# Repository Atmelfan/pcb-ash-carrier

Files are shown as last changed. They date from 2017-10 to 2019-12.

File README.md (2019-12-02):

# pcb-ash-carrier
ASH jetson TX2 carrier board. Imported from ASH-MKII

Main controller board for my octapod robot. 

[Schematic](https://raw.githubusercontent.com/Atmelfan/pcb-ash-carrier/master/schematic.PDF)

SAM Version revision 1 (May 2019):

IMAGE ALT TEXT (http://www.youtube.com/watch?v=Iza4ah-3IUo "SAM the octapod")

Carrier board:
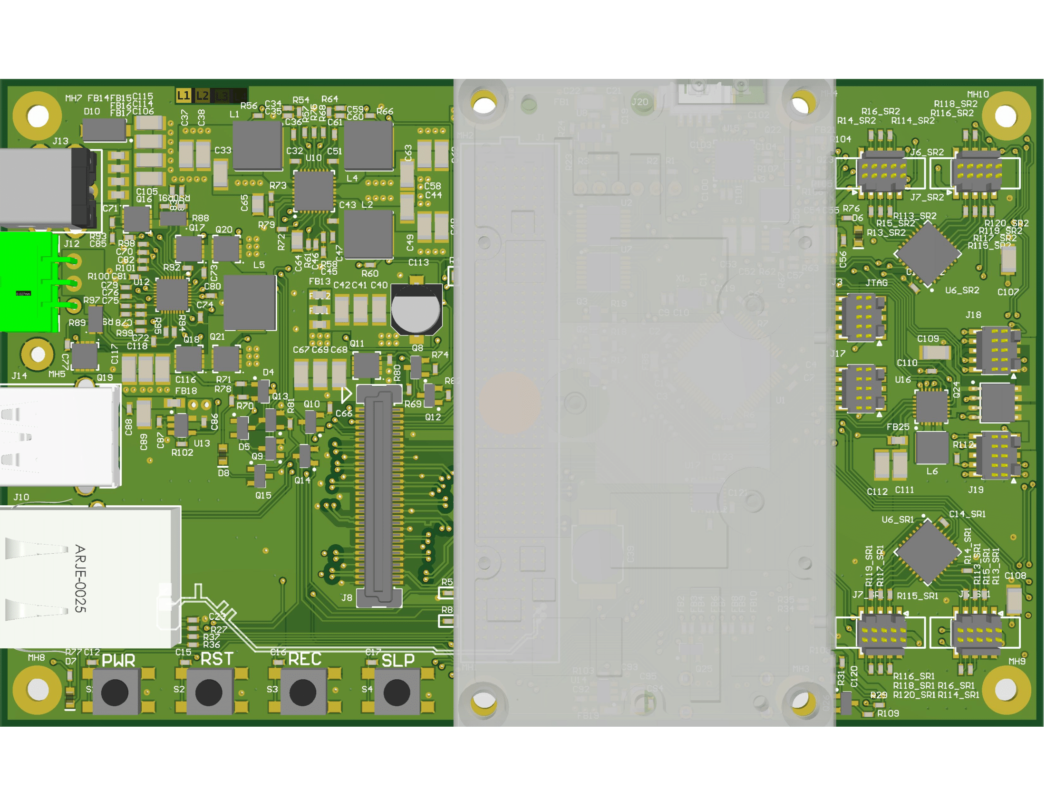
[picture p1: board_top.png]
Top side

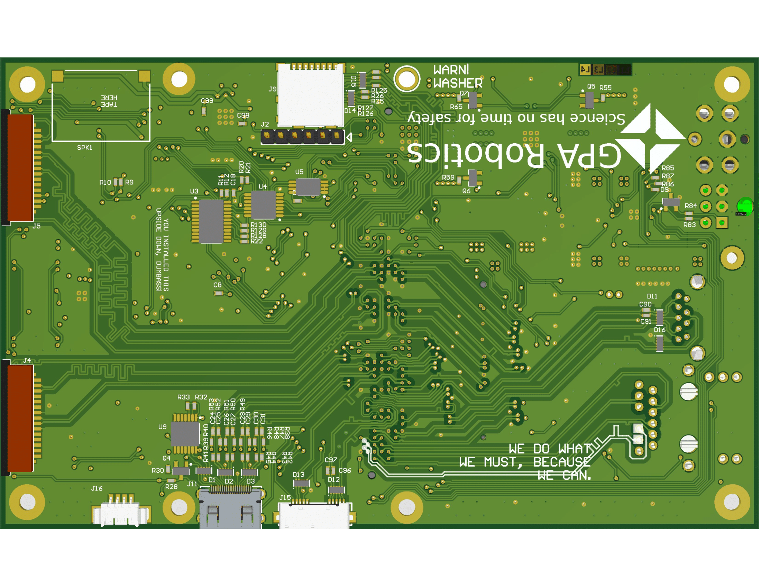
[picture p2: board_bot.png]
Bottom side


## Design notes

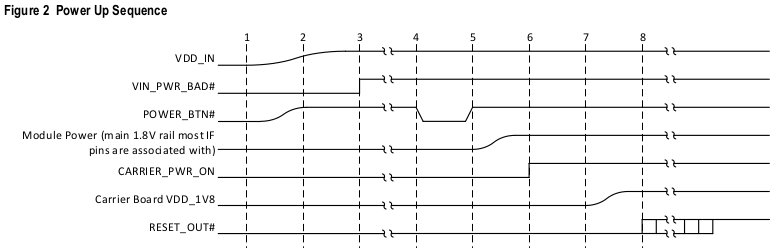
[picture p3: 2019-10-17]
tx_power_up.png

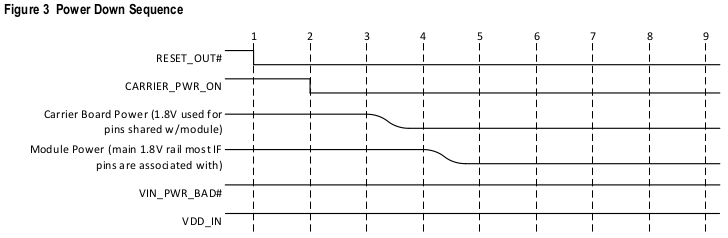
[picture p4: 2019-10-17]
tx2_power_down.png

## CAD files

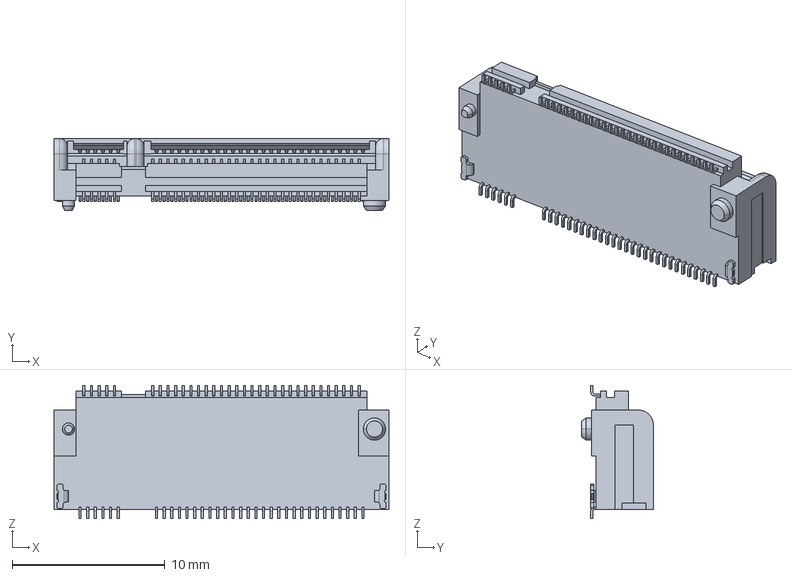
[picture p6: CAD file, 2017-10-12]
3d_models/c-2199230-5-b1-3d.stp
21.9 x 4.70 x 8.70 mm

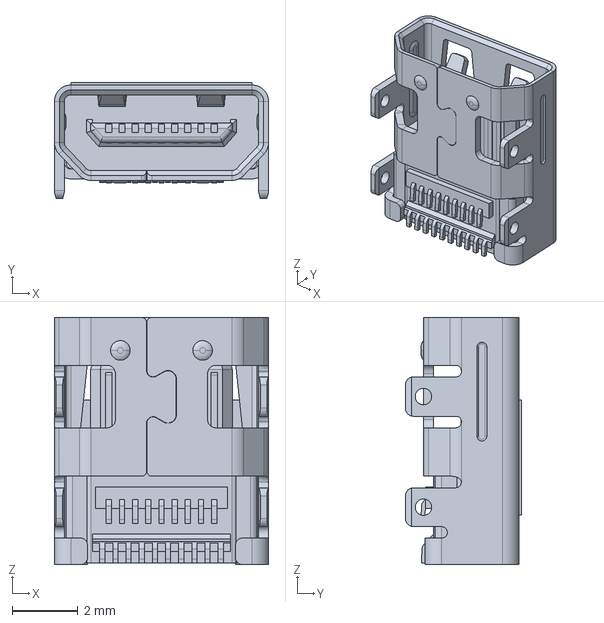
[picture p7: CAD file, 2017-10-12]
3d_models/10118242-001RLF.STP
6.50 x 3.53 x 7.50 mm

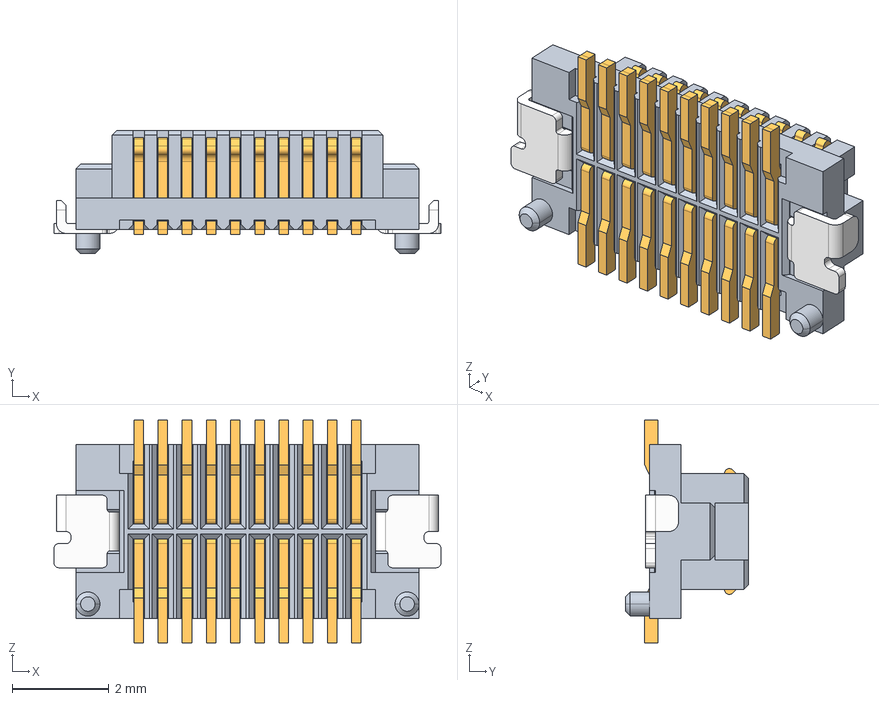
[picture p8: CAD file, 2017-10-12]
3d_models/10132798-021100LF.stp
8.00 x 2.55 x 4.60 mm
30H-20PIN-M-H
30H-M-TERMINAL x 10

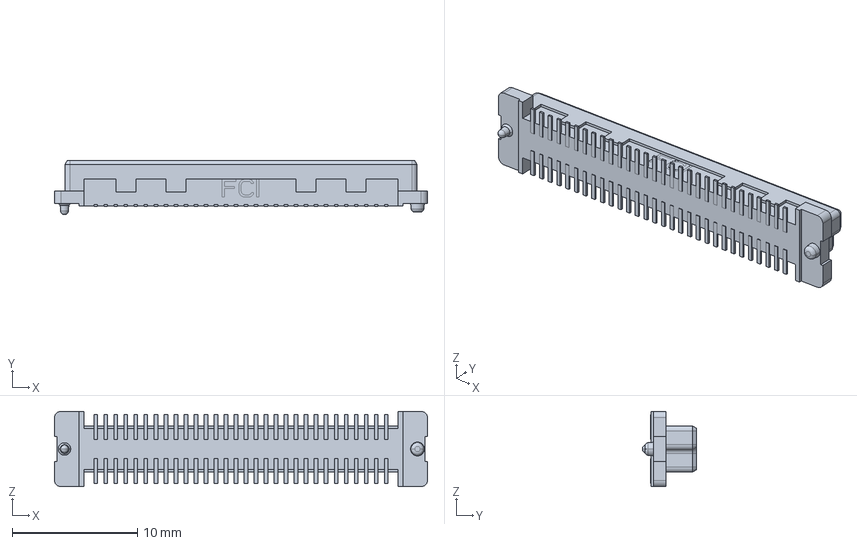
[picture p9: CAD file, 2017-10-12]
3d_models/s61082-061x0xxx.stp
29.8 x 4.35 x 6.00 mm

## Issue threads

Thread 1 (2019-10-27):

PSU sequence error

Atmelfan, 2019-10-27:
The PSU start sequence does not complete due to a missing pull-up.

Fixed in rev 1 prototype. Update schematic.

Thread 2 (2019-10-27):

Missing values

Atmelfan, 2019-10-27:
A lot of components (resistors in particular) does not have their final value.

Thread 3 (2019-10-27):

USB does not enable VBUS

Atmelfan, 2019-10-27:
USB VBUS never gets powered by the carrier. Most likely an error with the VBUS_EN# pins polarity or missing pull-up?

Might also be a firmware error.

Atmelfan, 2020-04-07:
Firmware error, the dbt requires a vbus-regulator which does not exist on the board.

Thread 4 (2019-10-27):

Voltage translator does not work/prevent boot

Atmelfan, 2019-10-27:
Voltage level converters U2/U7 keeps the TX2 from booting. Most likely caused by UART1_TX being pulled up by U2 on boot.

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

Atmelfan, 2019-10-27:
UART7 is also affected by U7.
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

Atmelfan, 2020-01-20:
Most of these issues is caused by LSF/TXB0204 are used to translate both Push-poll and Open-drain IO:s which is incorrect. Split the IO:s between multiple appropriate translators.

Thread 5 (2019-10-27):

GYRO has incorrect footprint and uses a NRND part

Atmelfan, 2019-10-27:
Switch MP6000 to MP9250 (or equivalent) with a correct footprint.

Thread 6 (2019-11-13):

Add RS485 transciever(s)

Atmelfan, 2019-11-13:
New servos uses RS485 for communication and will thus require a transciever on the carrier.
Prefably both the jetson TX2 and the onboard MCU will be able to commicate with the servos (or eachother).

Possible solutions:
1. Jetson TX2 and the MCU get their own transciever connected to a shared bus.
2. A single transciever sharedby jetson and the MCU.
3. MCU forwards commication from serial interface (will require a custom driver in TX2 firmware)

ATM option 1 looks like the best solution.

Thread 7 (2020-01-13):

Add servo ports for eyes

Atmelfan, 2020-01-13:
Both right and left servo control has unused PWM outputs.

Supply should be taken from VBAT with its own step-down converter. Alternatively tap into VSYS_5V0 but this could result in a lot of noise on USB ports.

Atmelfan, 2020-04-07:
Added to pcb-ash-power

Closed 2020-04-07.

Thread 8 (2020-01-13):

Replace NVM screw standoffss with solder standoffs

Atmelfan, 2020-01-13:
^

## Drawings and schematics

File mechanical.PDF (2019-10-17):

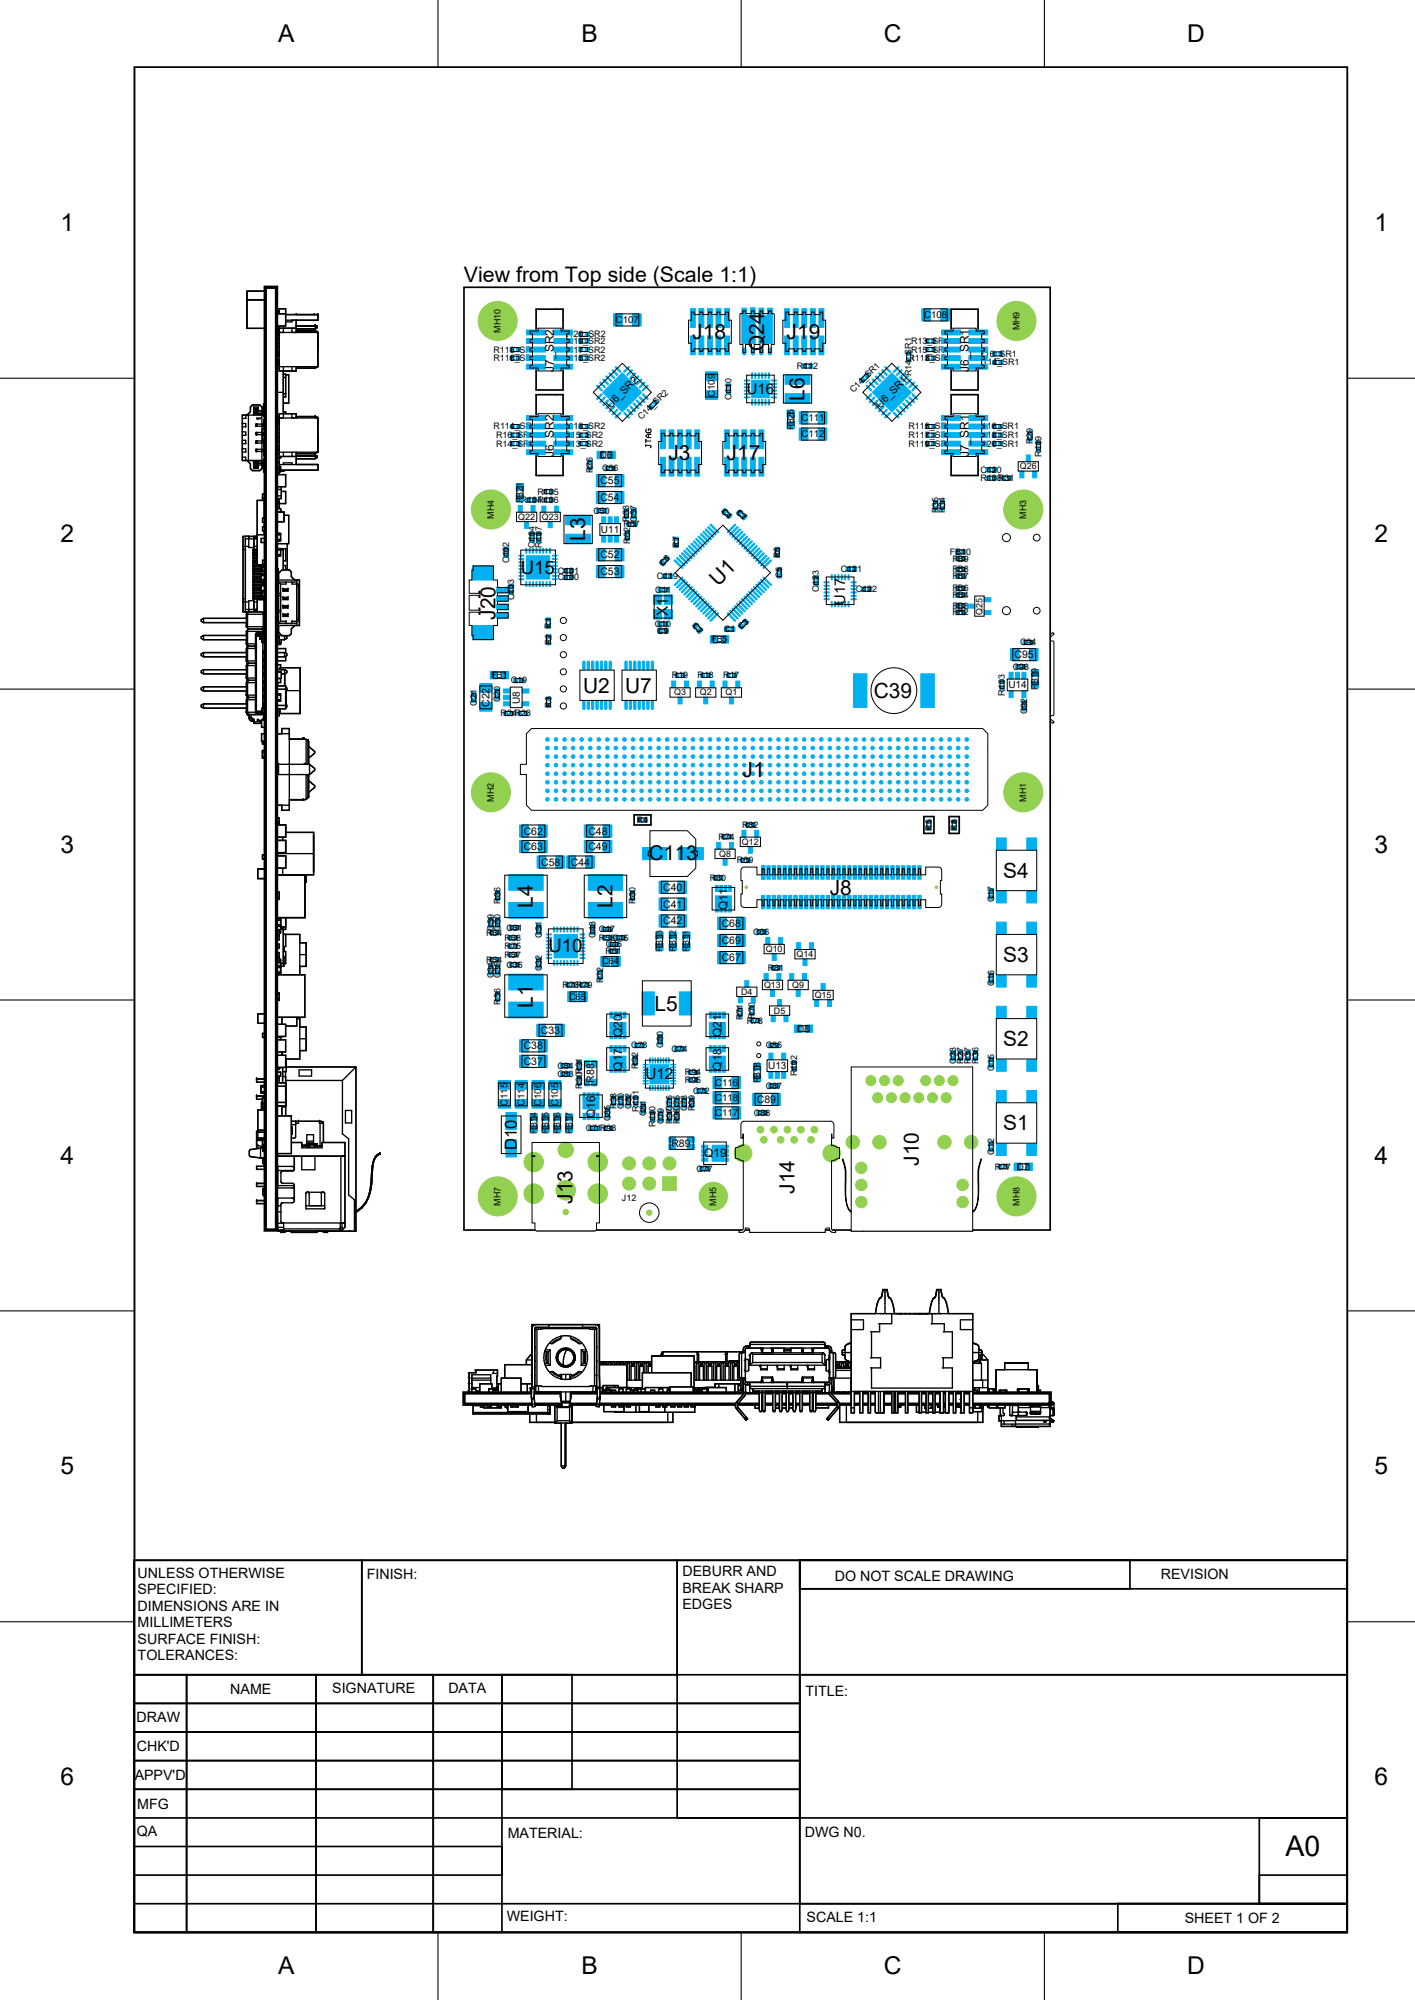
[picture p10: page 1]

View from Top side (Scale 1:1)

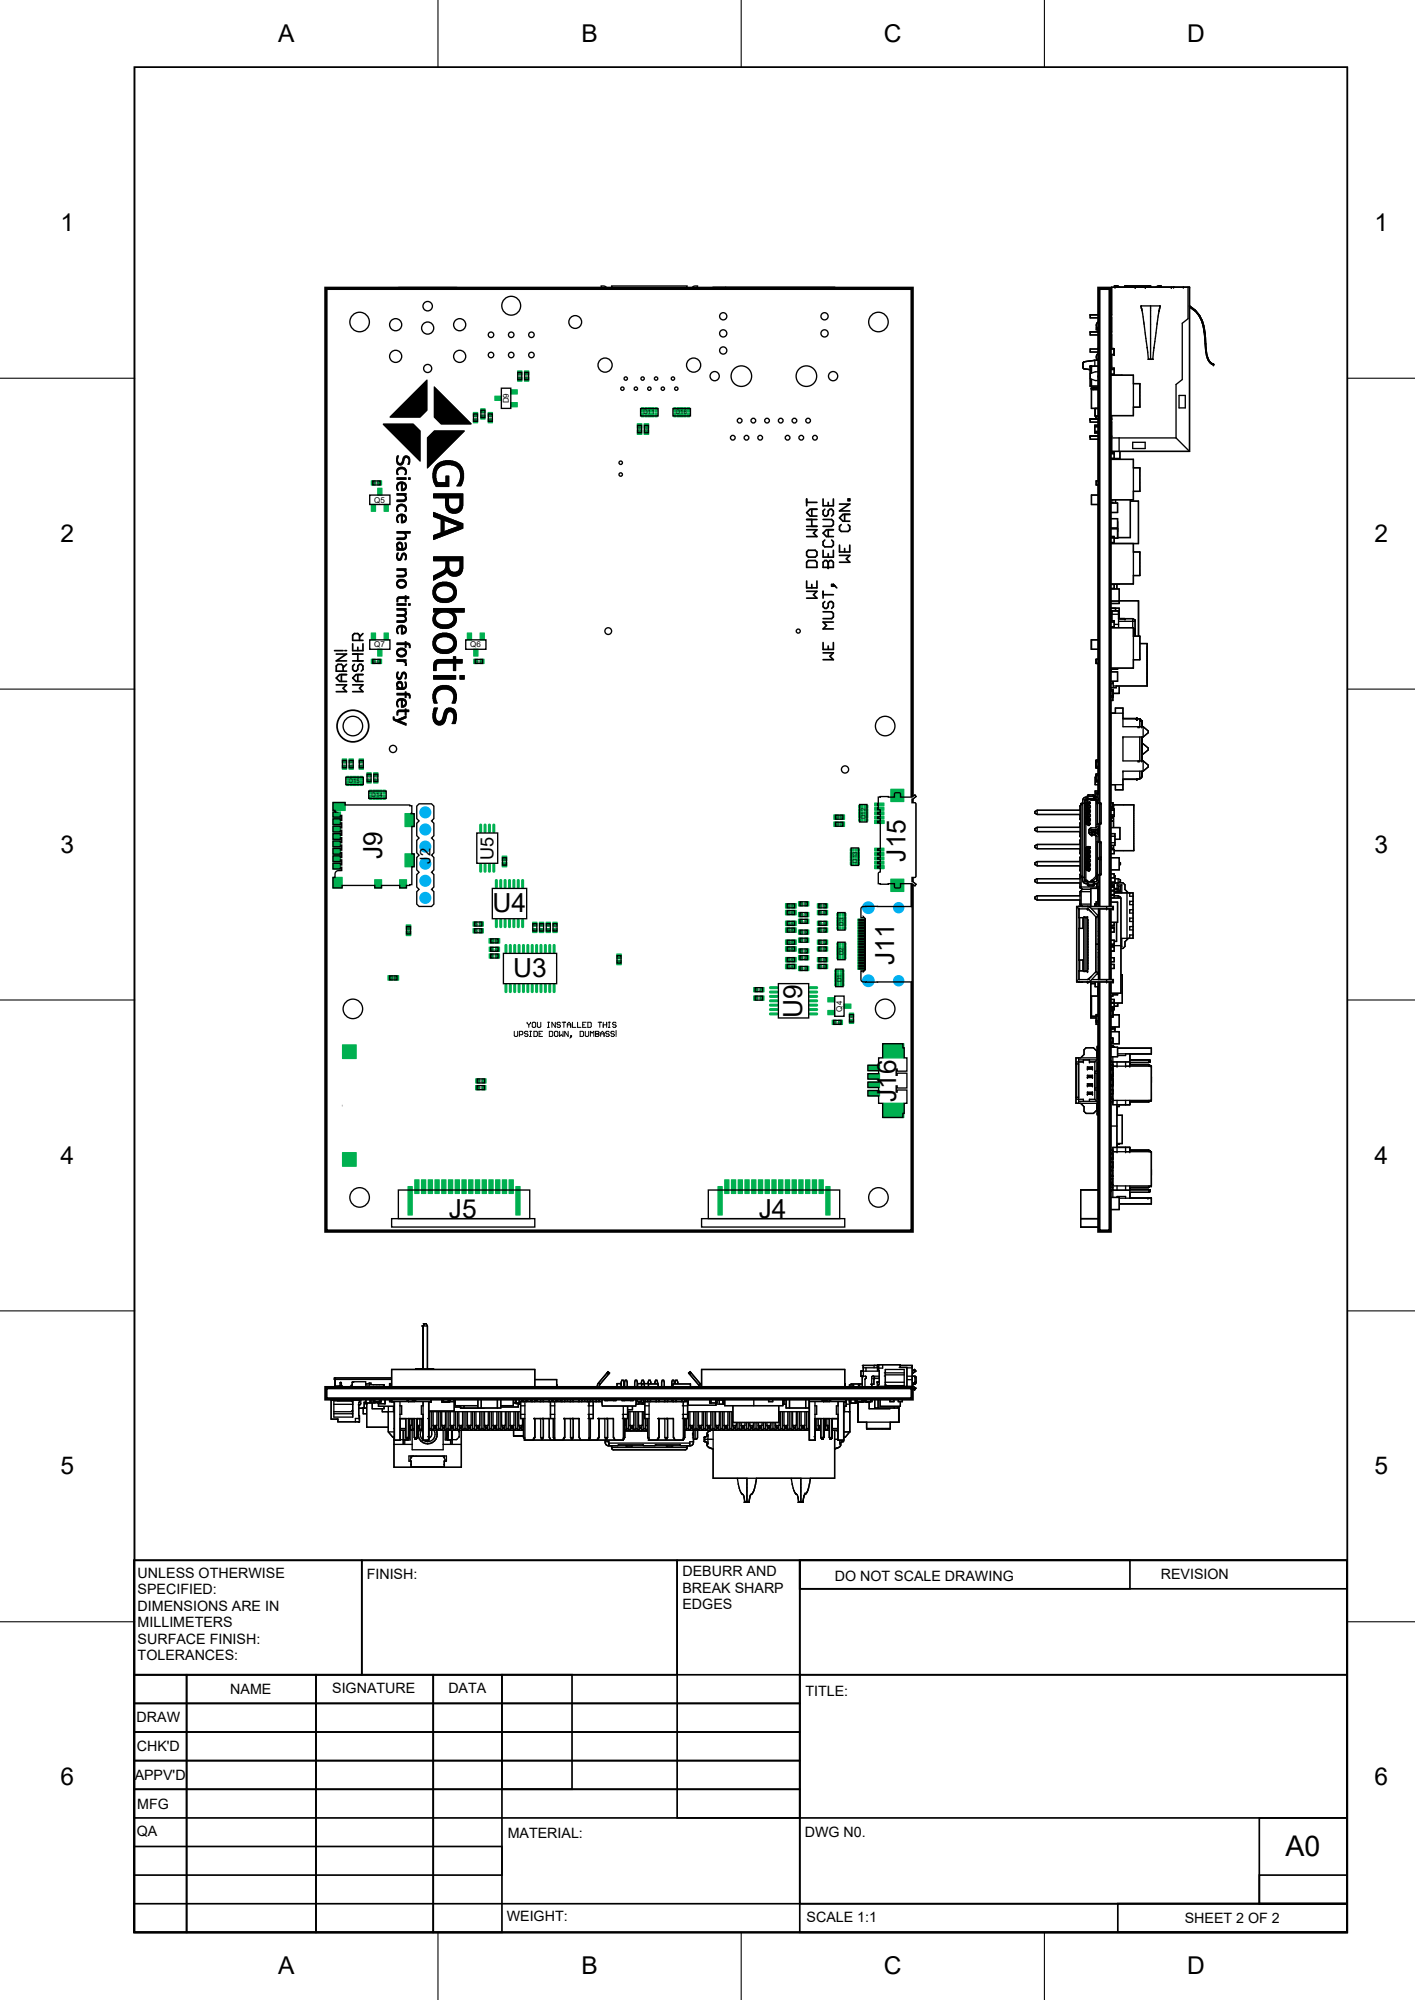
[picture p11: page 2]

NAME | SIGNATURE | DATA | | | | TITLE:

DRAW
CHK'D

APPV'D
MFG
QA | | | | MATERIAL: | DWG N0. | A0

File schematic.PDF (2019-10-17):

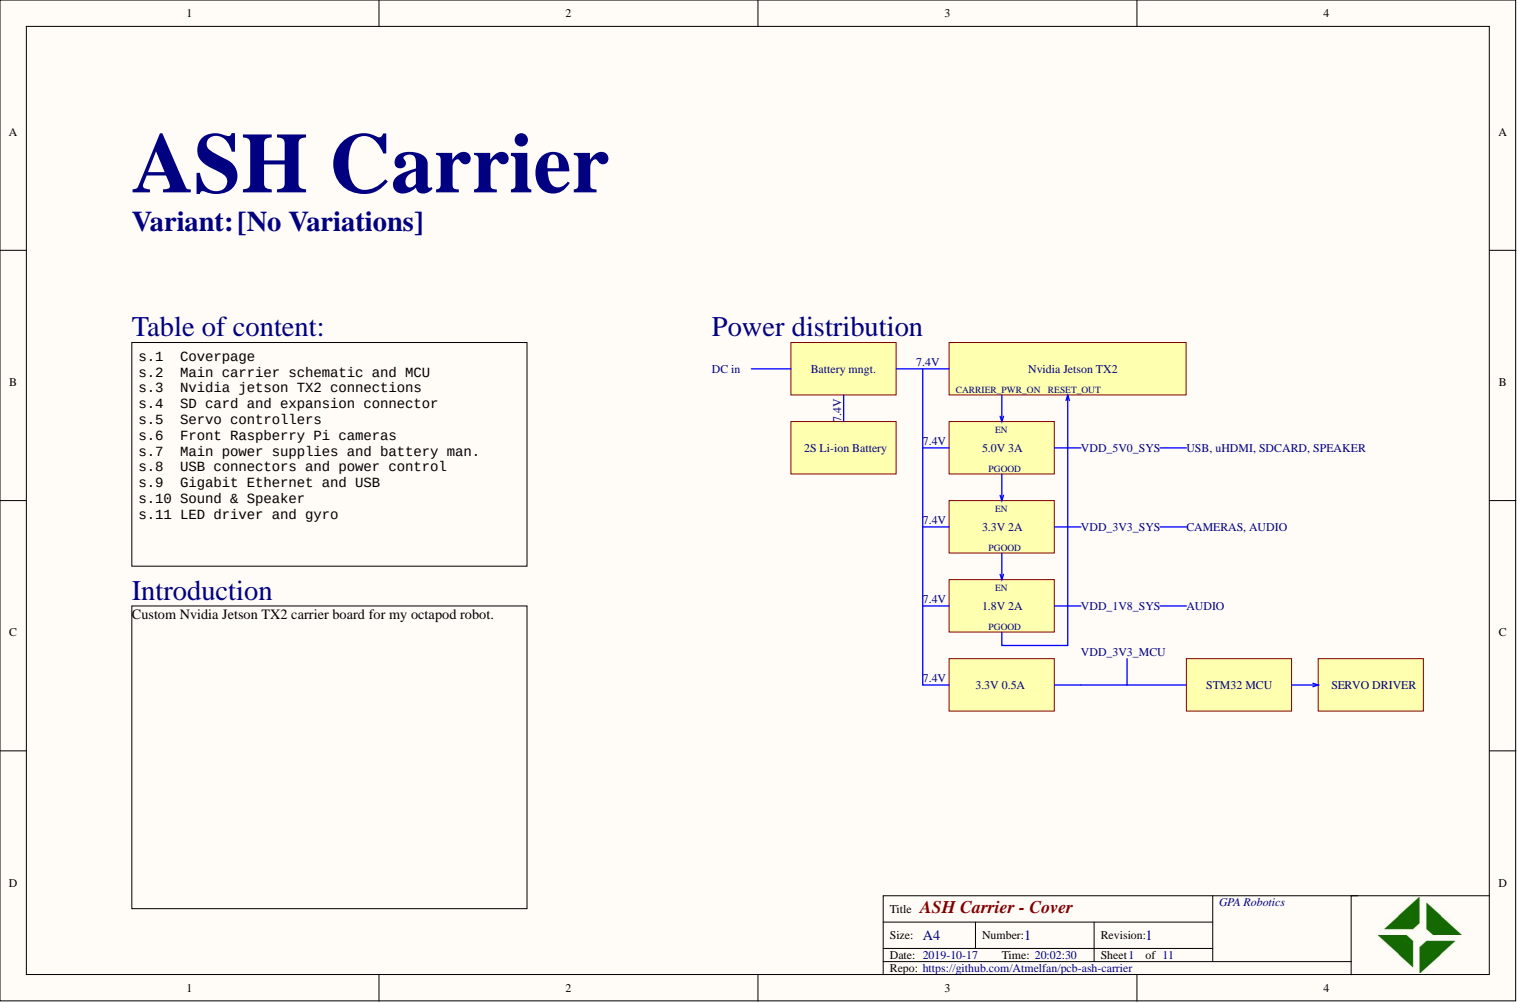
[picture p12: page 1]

s.10 Sound & Speaker
s.11 LED driver and gyro

USB, uHDMI, SDCARD, SPEAKER

Custom Nvidia Jetson TX2 carrier board for my octapod robot.

Title ASH Carrier - Cover | GPA Robotics

Size: A4 | Number: | Revision:
Date: 2019-10-17 Time: 20:02:30 | | Sheet of

https://github.com/Atmelfan/pcb-ash-carrier

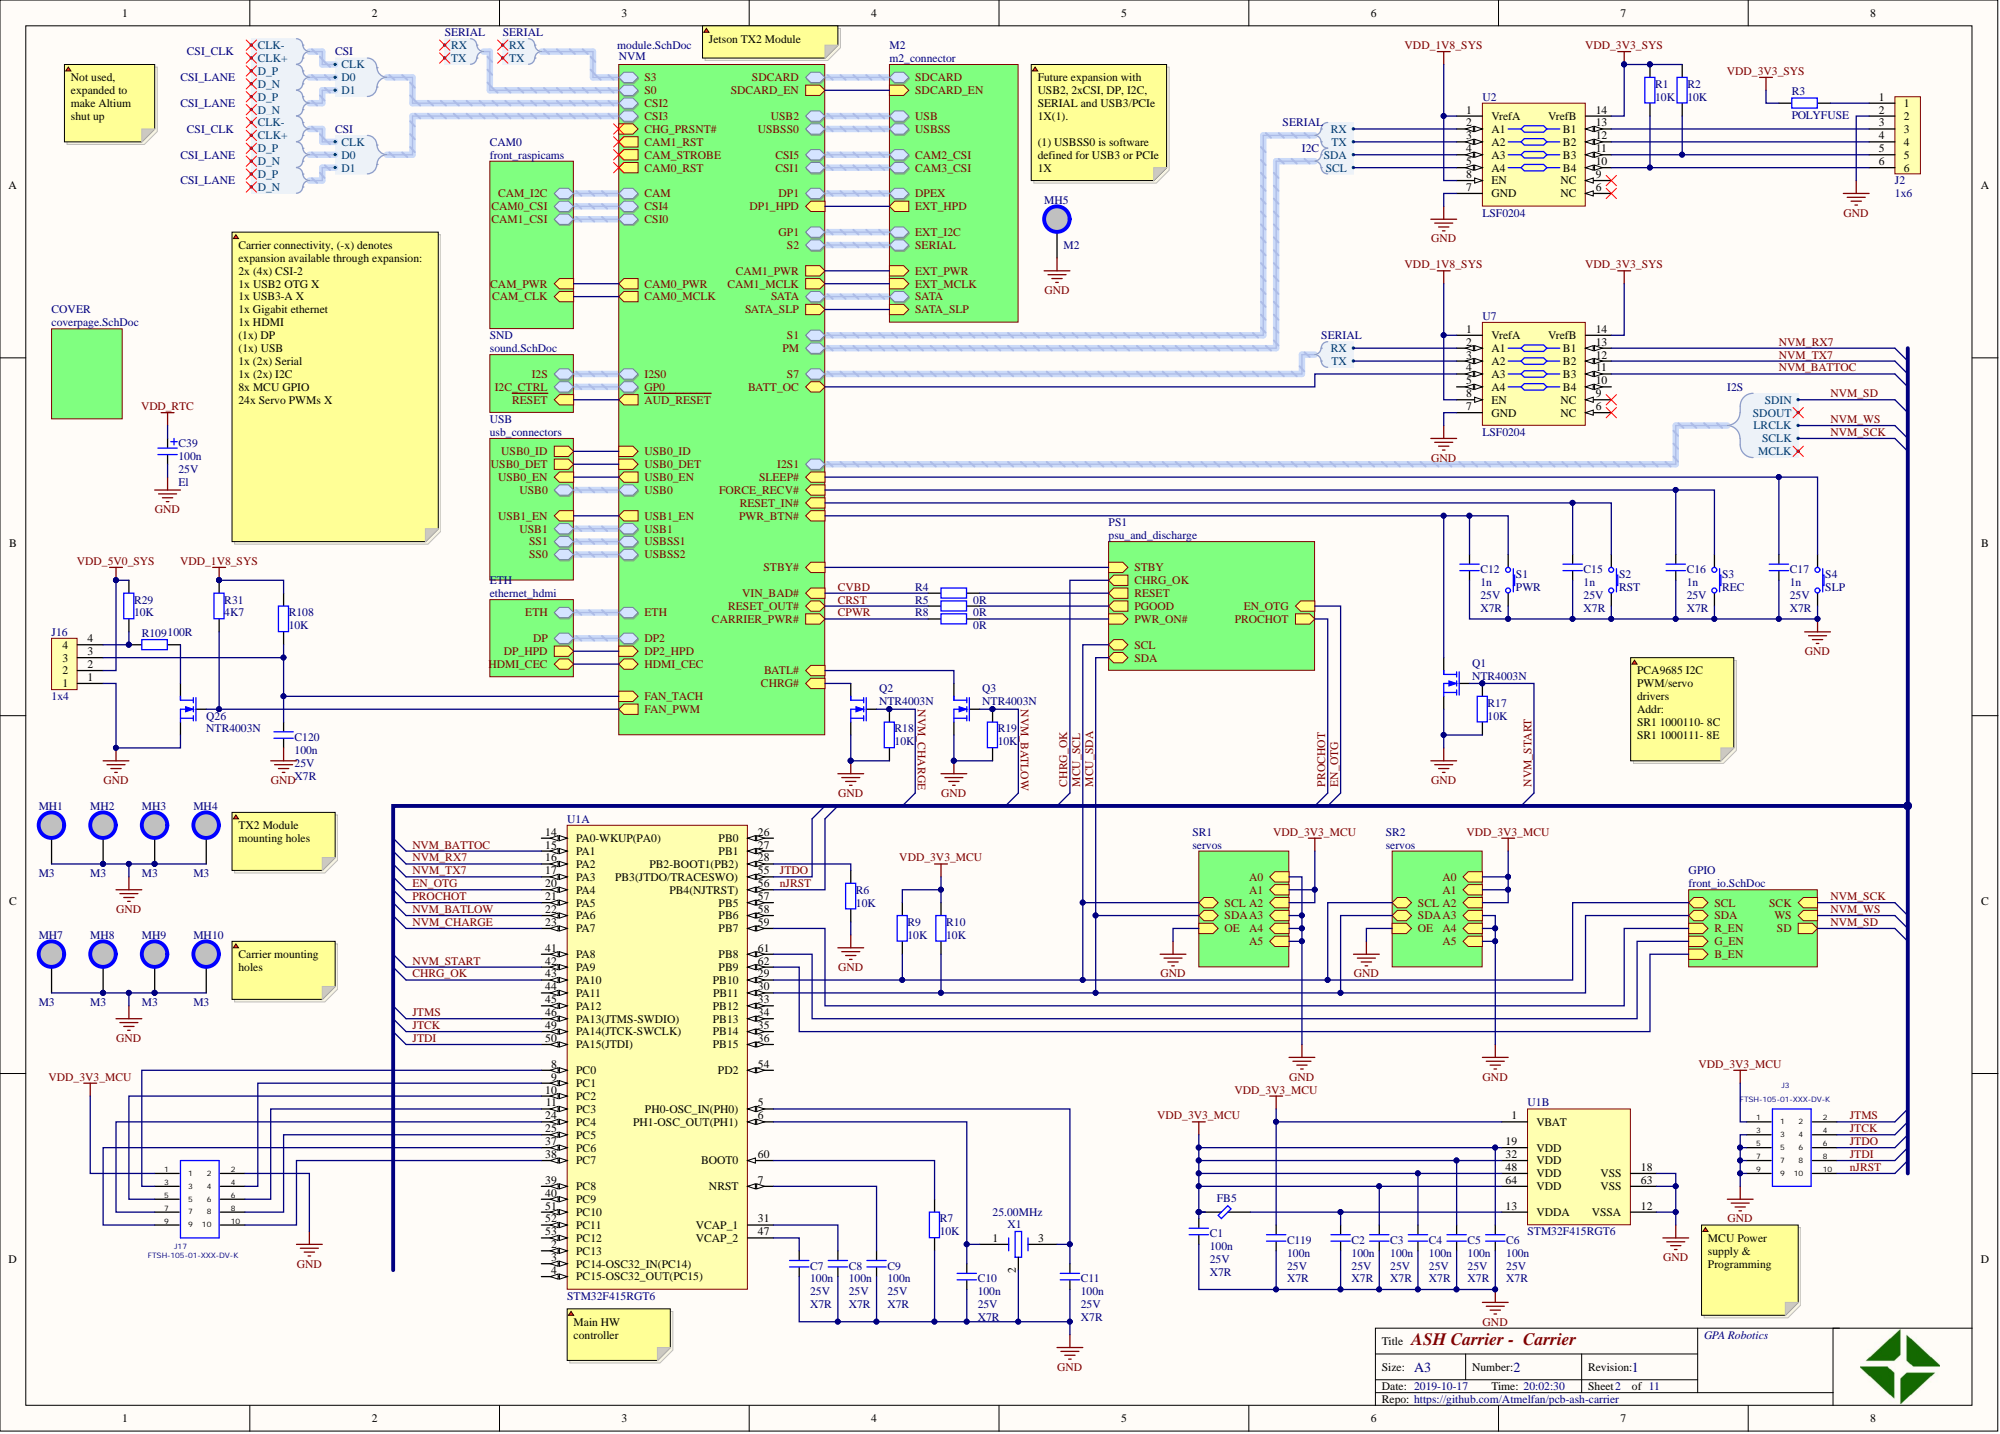
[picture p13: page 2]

(1) USBSS0 is software
defined for USB3 or PCIe

CRST R5 | 0R
CPWR R8 | 0R

SDA A3 | NVM_WS
OE A4 A5 | | NVM_SD

PC1 9
PC2 10

5 5 6 | 6 | PC9 40
7 7 8 | 8 | PC10 51
9 9 10 | 10 | PC11 52

PC15-OSC32_OUT(PC15) 4 | C10 | X7R | X7R | X7R | X7R | X7R | X7R

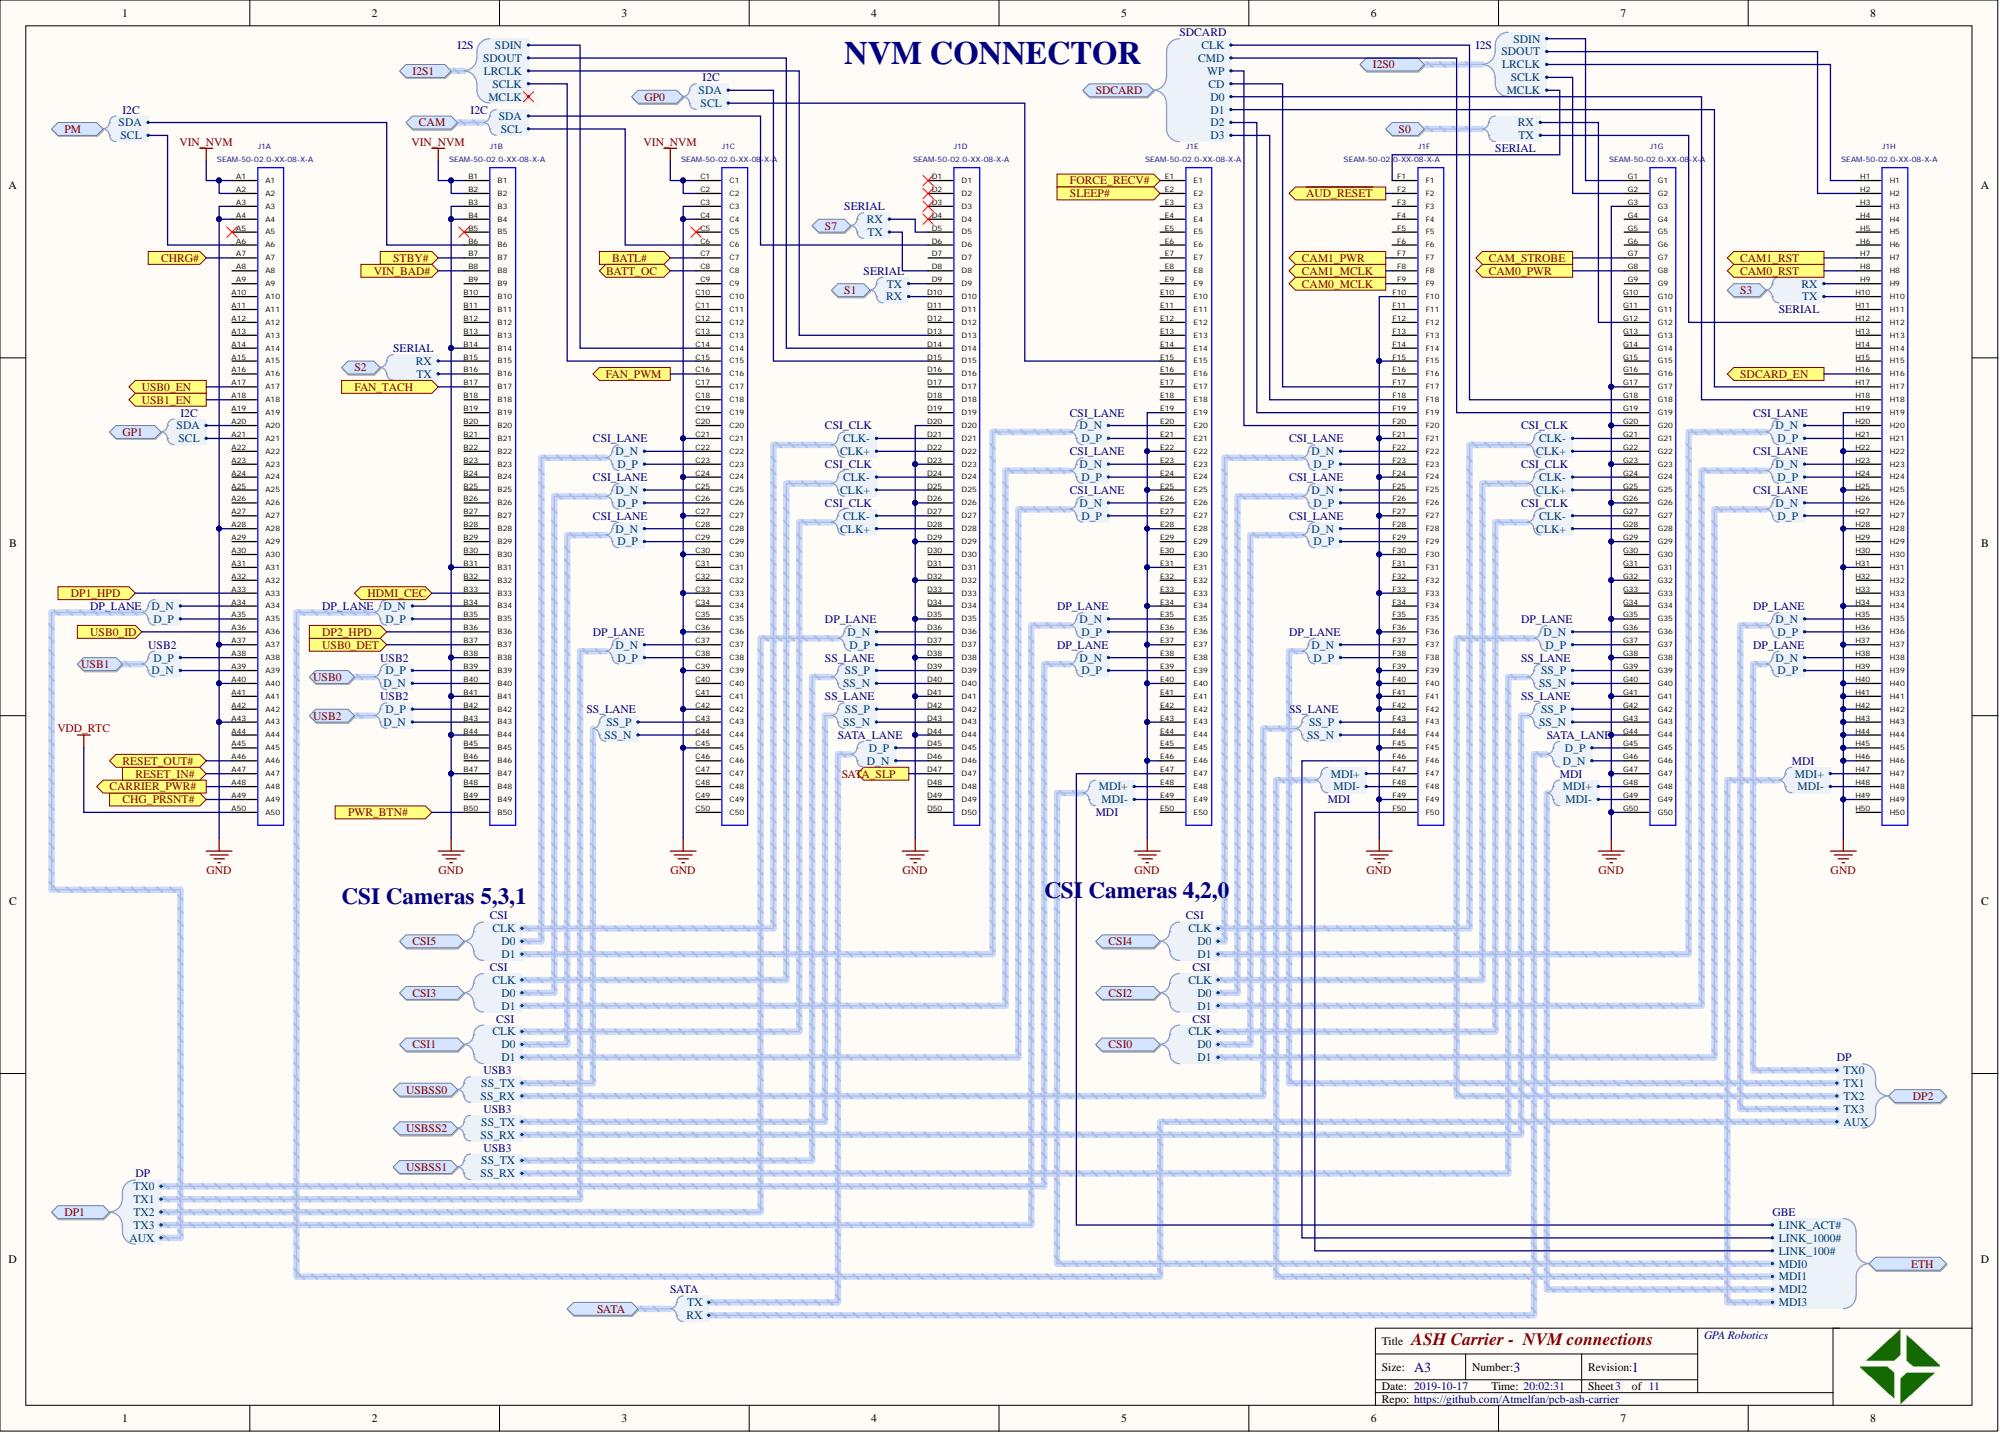
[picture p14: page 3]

SDOUT

I2S0 LRCLK

SEAM-50-02.0-XX-08-X-A | J1D

ASH Carrier - NVM connections
Title

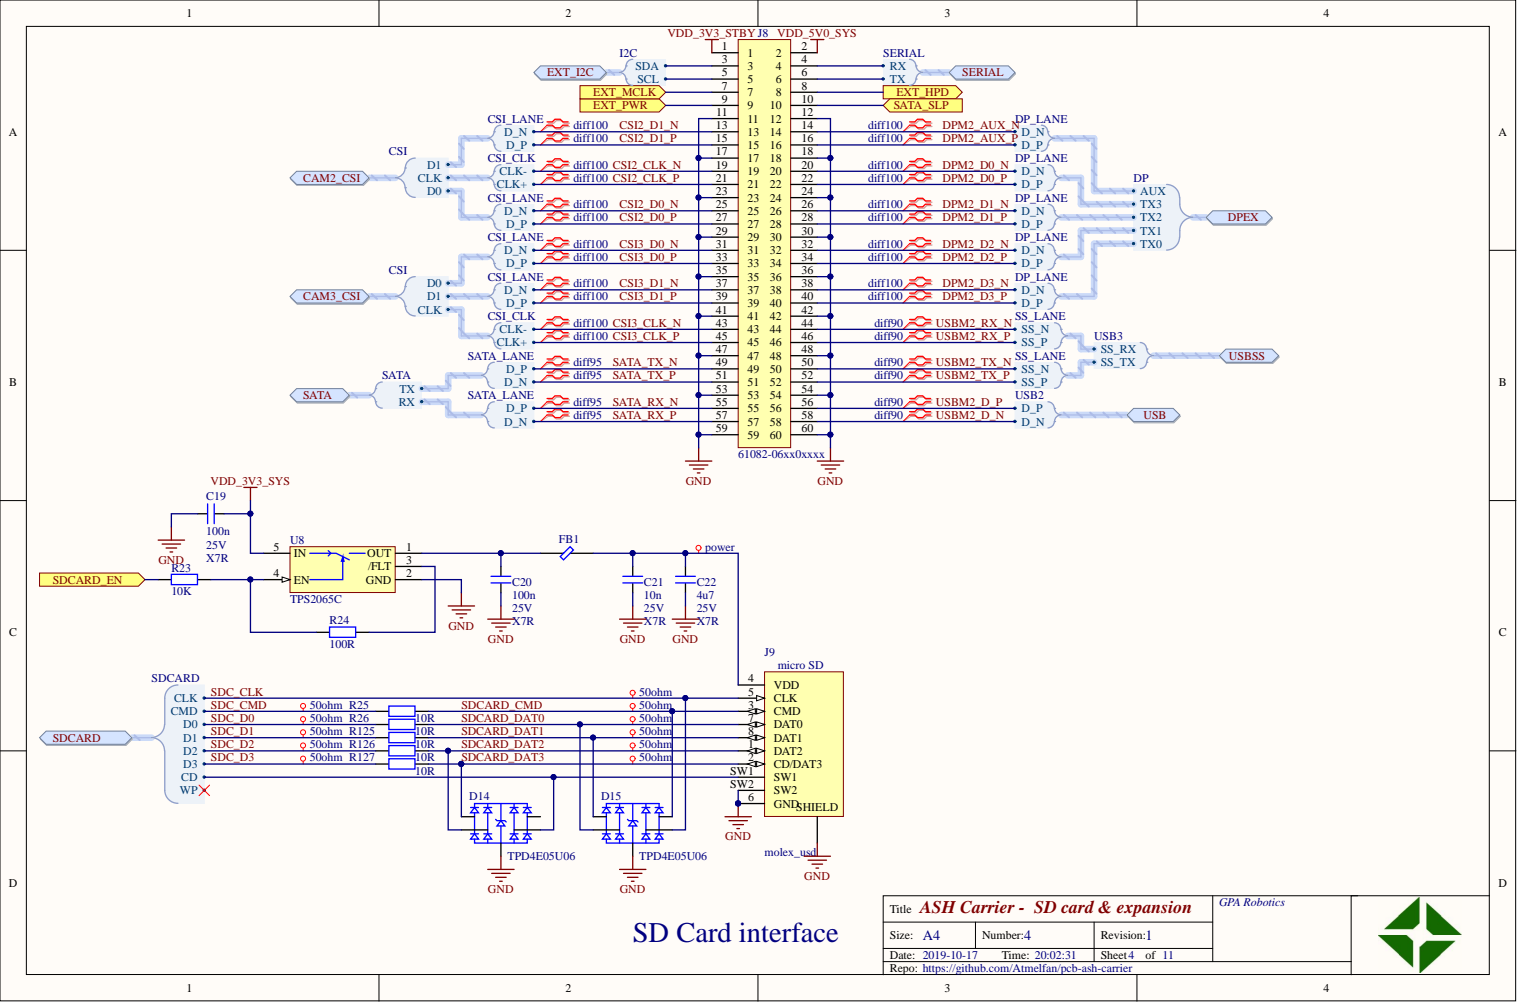
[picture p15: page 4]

CMD 3

10R SDCARD_DAT1 | 50ohm | | DAT1 8
10R SDCARD_DAT2 | 50ohm | | DAT2 1

ASH Carrier - SD card & expansion
Title

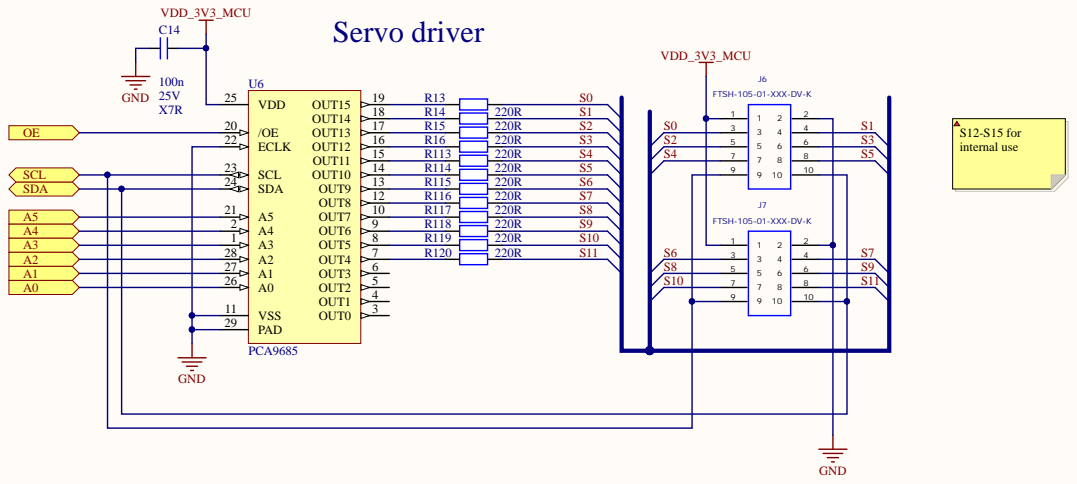
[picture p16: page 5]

ASH Carrier - Servo driver 5
Title

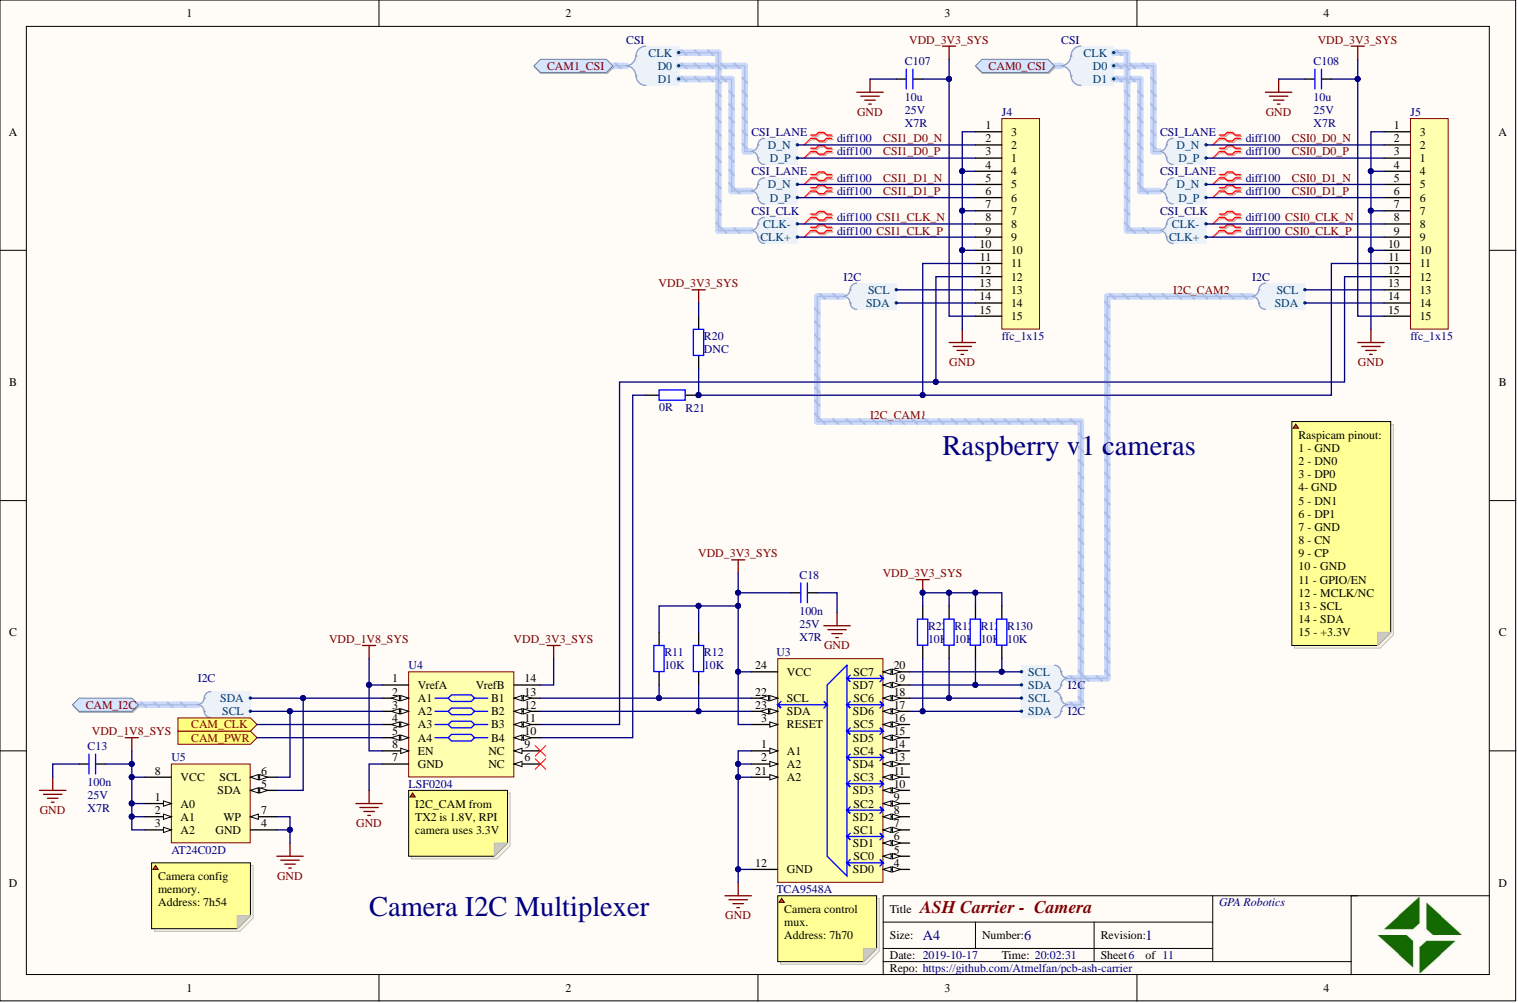
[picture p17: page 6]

9 9
10 10

A3 4 A4 5 | RESET 3

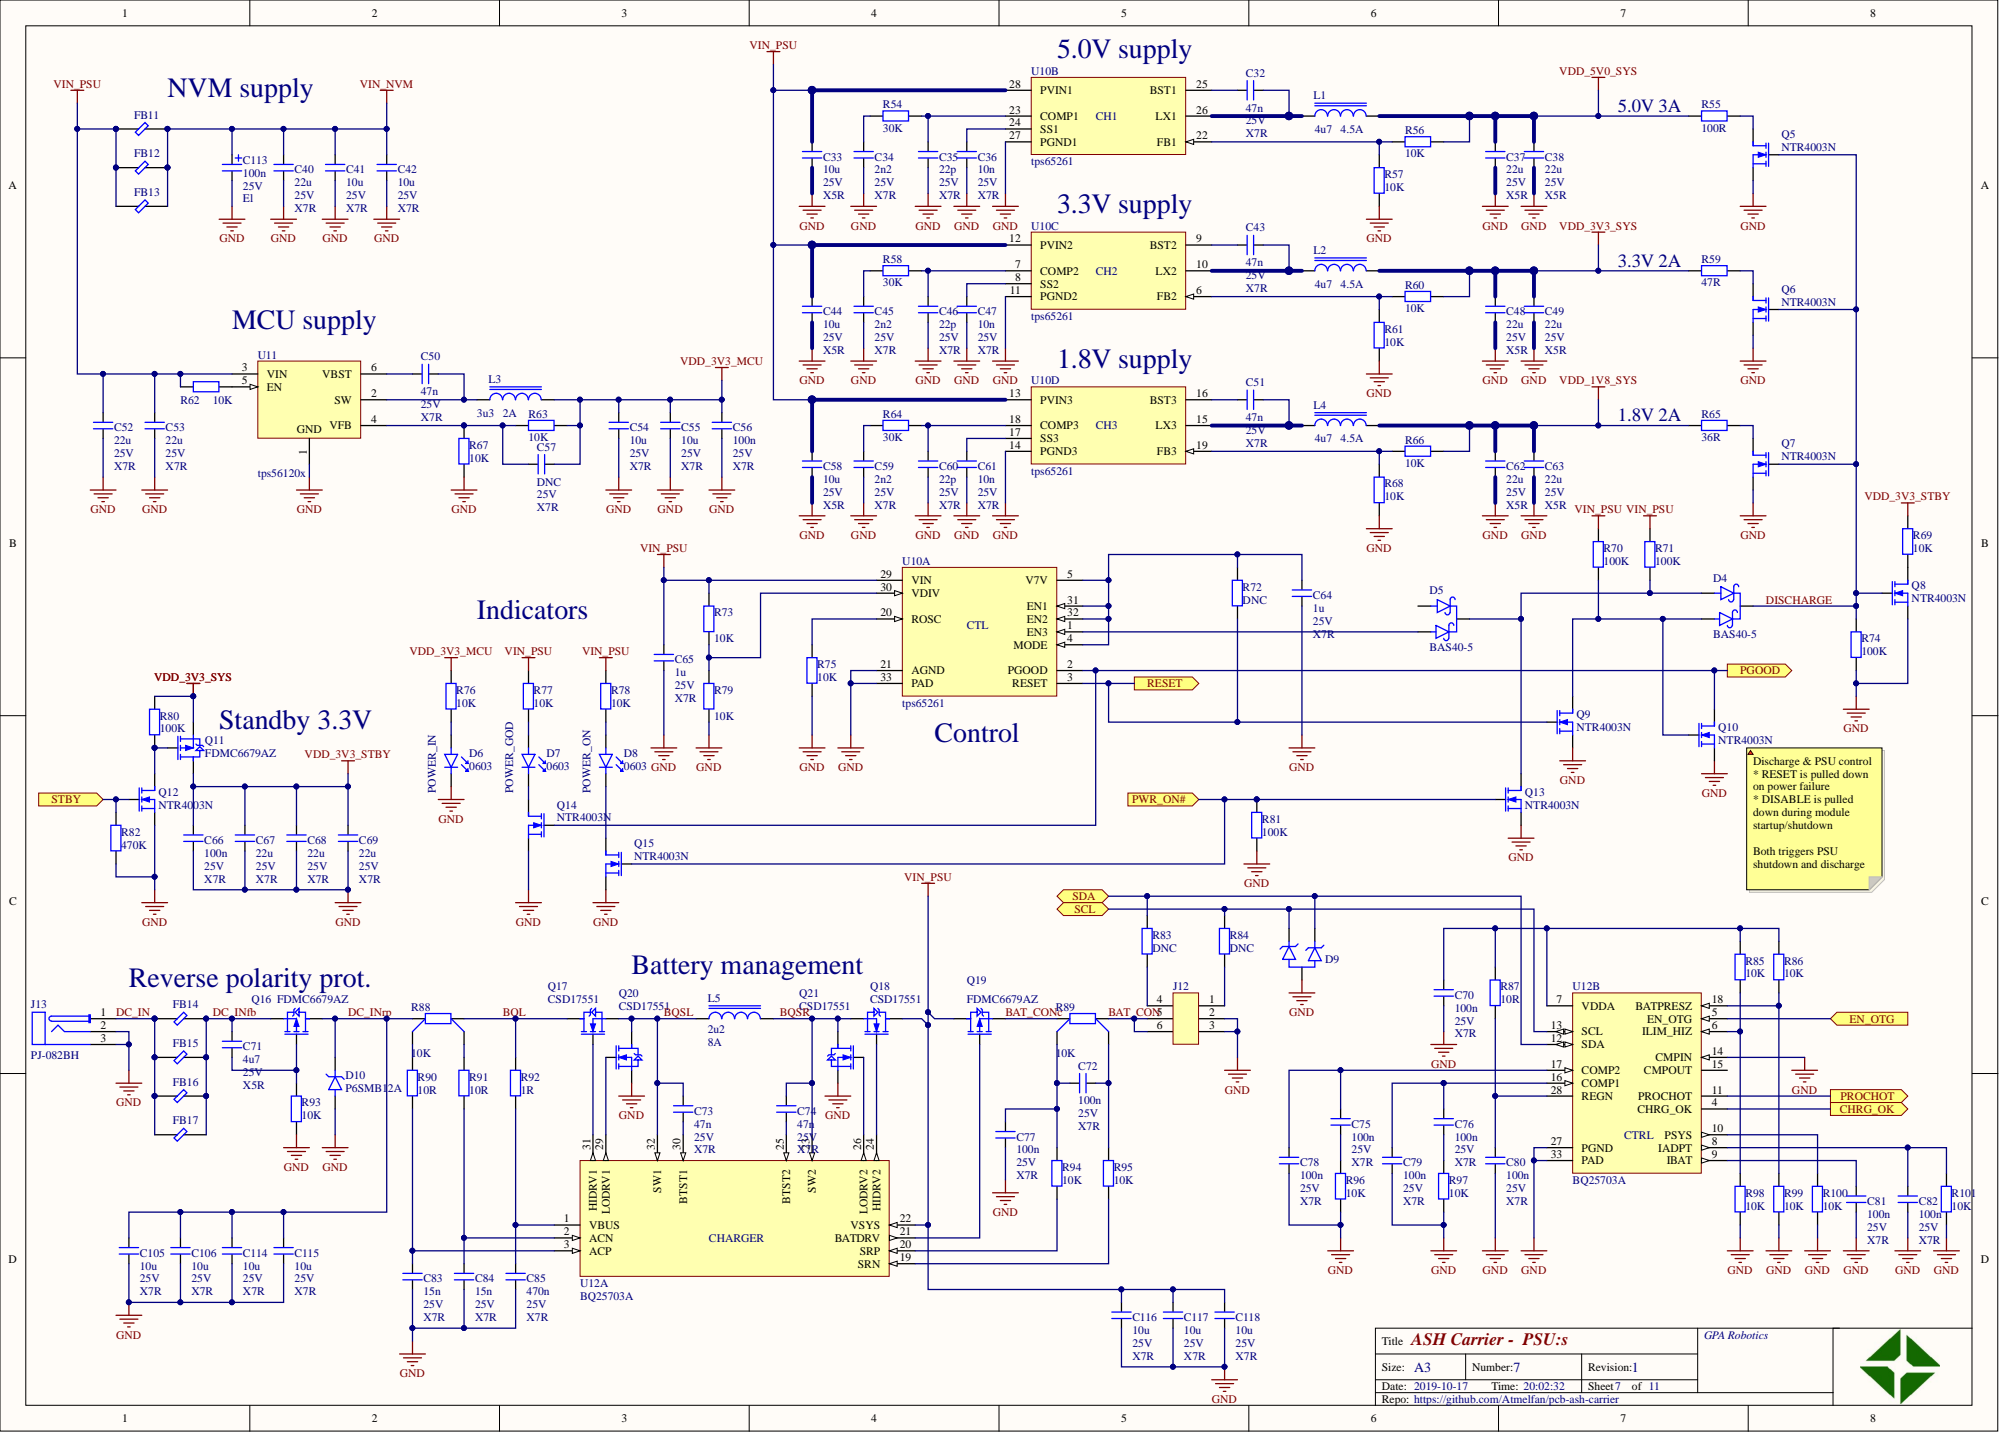
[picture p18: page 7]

R58 | | COMP2 7 | 47n

GND | | | C51

R64 | | SS3 17 COMP3 18 | 47n

ROSC 20

D8 0603 | | PAD 33

Discharge & PSU control
* RESET is pulled down
on power failure
* DISABLE is pulled
down during module
startup/shutdown

GND
Battery management Reverse polarity prot.

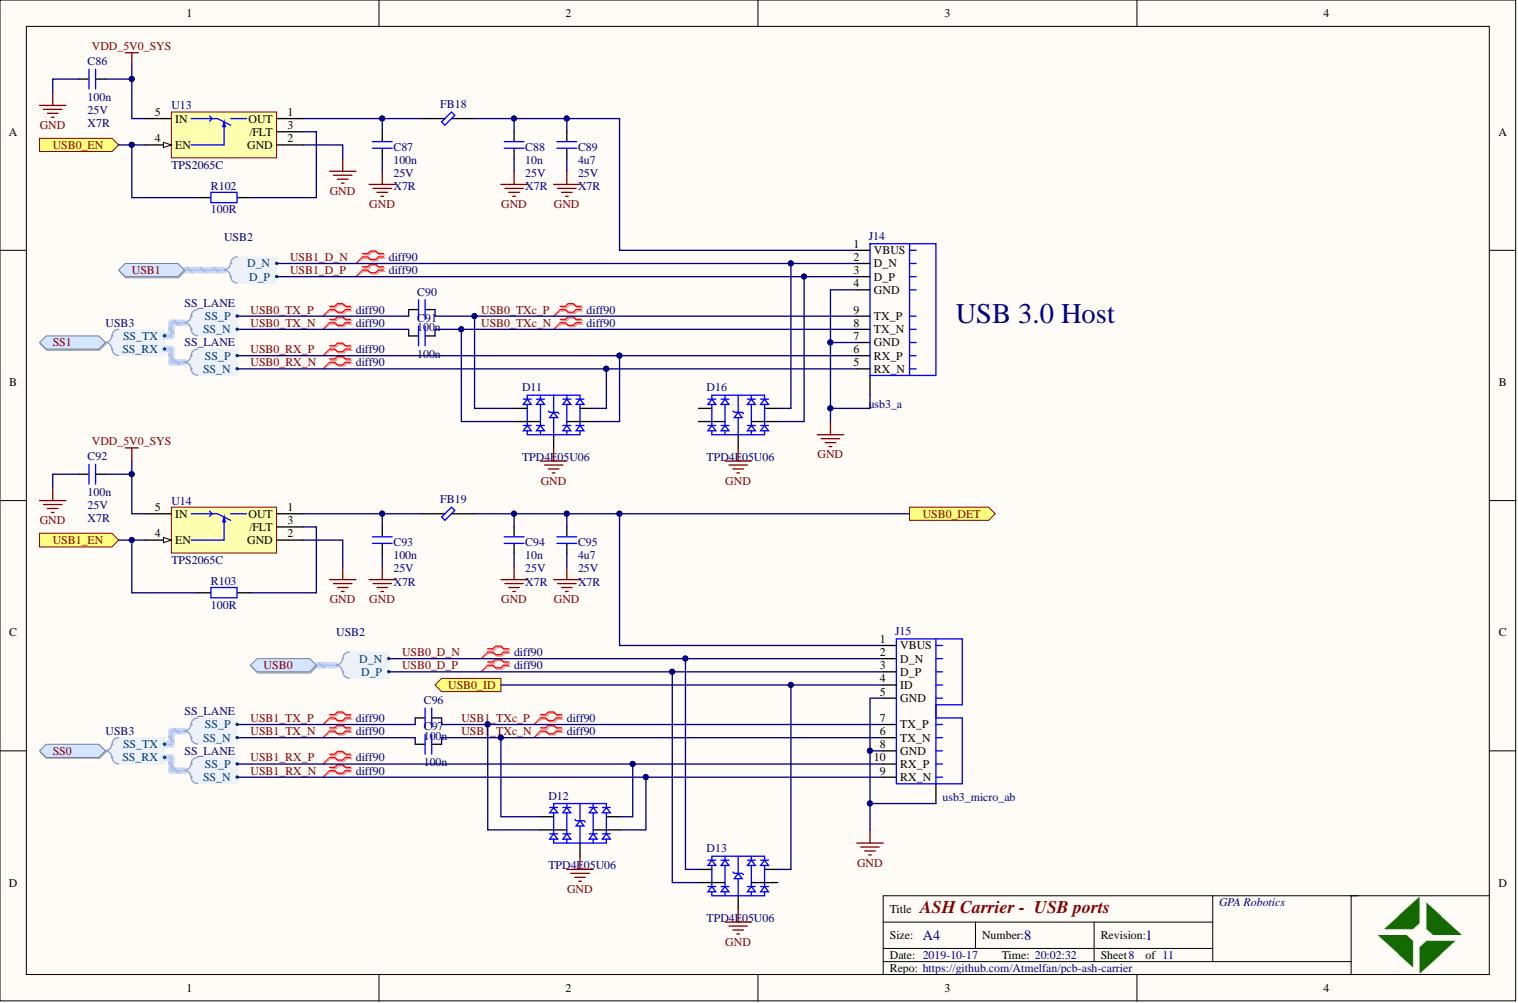
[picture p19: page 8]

D_N 2
D_P 3
GND 4

USB0_TXc_N | diff90 | | | TX_N 8

GND 7
RX_P 6
RX_N 5

GND 5

TX_P 7 TX_N 6 GND 8

ASH Carrier - USB ports
Title

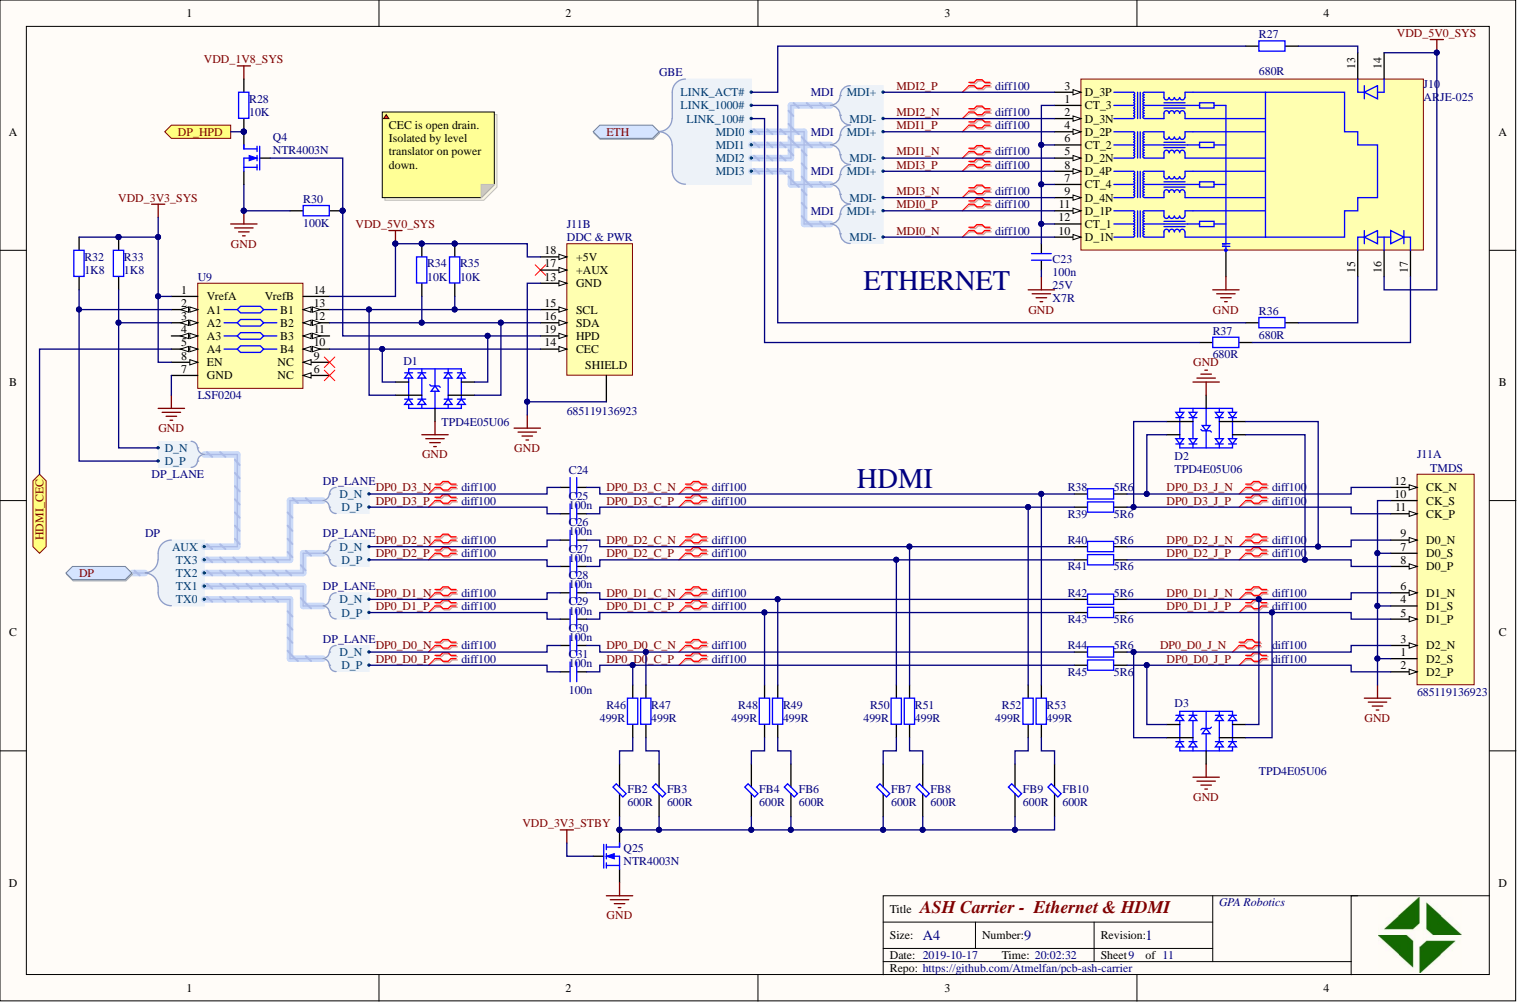
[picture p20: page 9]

MDI2_N diff100 | 2 | CT_3
MDI1_P diff100 | 4

CEC is open drain.
Isolated by level
translator on power
down.

3 | SDA 16

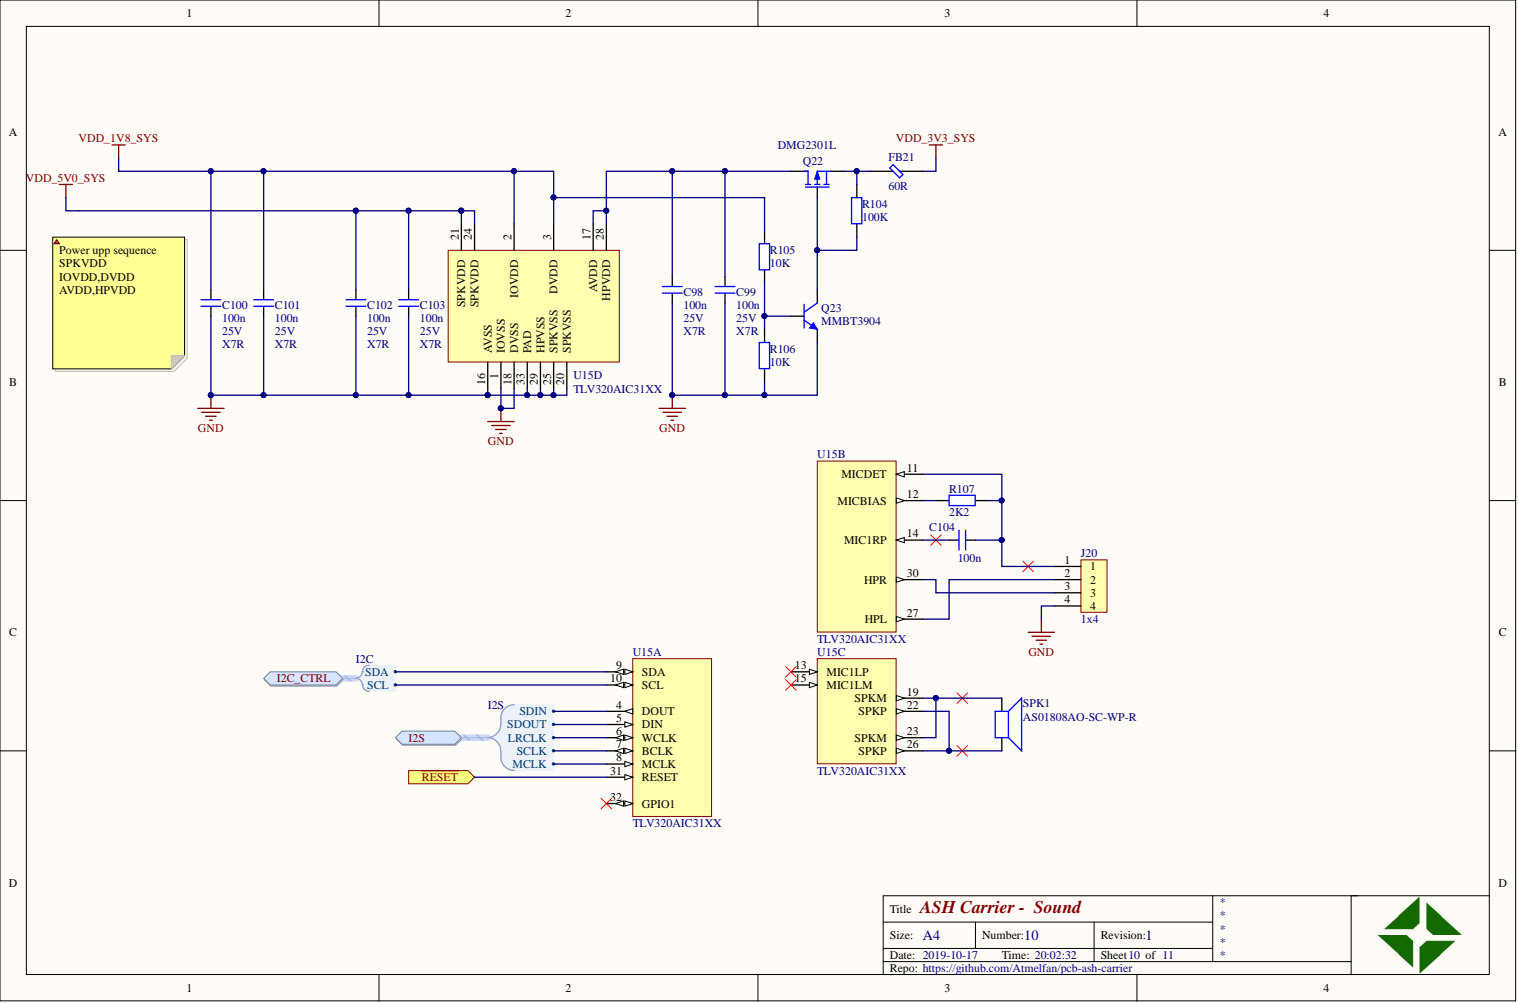
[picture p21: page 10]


C112 | | SCL 21

AUX_D AUX_C

CLKIN 1 | 6 7

FSYNC 11

ASH Carrier - LED driver & Gyro
Title

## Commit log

2017-10-12 Initial
    Initial commit
    [10118242-001RLF.STP, 10132798-021100LF.stp, c-2199230-5-b1-3d.stp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]
2019-10-17 Moved libraries to libs/
    [carrier.PrjPcb]
2019-10-17 Updated schematic templates and fixed some PCB models
    [carrier.PrjPcb, carrier.SchDoc, coverpage.SchDoc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]
